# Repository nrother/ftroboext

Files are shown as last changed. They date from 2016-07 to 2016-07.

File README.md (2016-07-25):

# ftroboext
Self-made fischertechnik Robo Extension based on a ATmega328

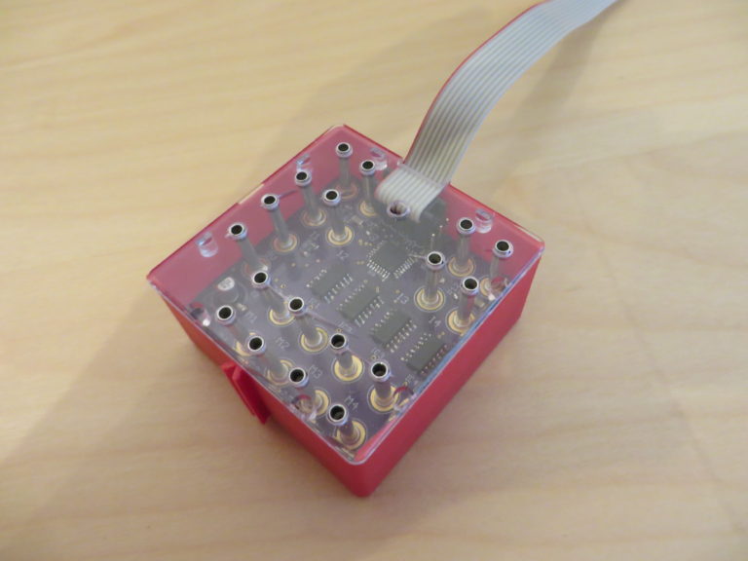
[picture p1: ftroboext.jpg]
Photo of ftroboext
 

I own a RoboInterface (yes, the old) from fischertechnik, but no
Extension module for it. It's difficult to find some now, so I build
my own. This repository contains the hardware as EAGLE files and the
software as an Arduino sketch. The PCB is designed to fit nicely into
a box (Art.Nr. 130961).

More information (in german) can be found on [my blog](http://niklas-rother.de/tags/ftroboext/).

I currently have two unpopulated PCBs here, contact me if you have interest
in them.

## Hardware
The hardware is quite packed because it has to fit inside the box. This is
also the reason why there are only four inputs (I1-I4). Everything is SMD
for the same reason, but can be hand-soldered quite well, the biggest problem
is the ATmega, but it is doable.

The hardware has a few bugs, see below. Some will be fixed in a new revision,
some are impossible to fix. The biggest problem is, that the voltage on
O2,O4,O6 and O8 can not be controlled, they are always the same as O1,O3,O5 and O7.
This is because the driver has only one enable pin for both outputs, a fact I
missed when selecting the chip.

### Revision A
* Footprint for C2 is wrong (too large)
* Footprints for the connectors are a bit large
* EXT header is mirrored/label is wrong
* The `/SS` pin is not pulled low. To fix this, cut the `ADDR1` pin from the header, solder
it to GND (the pin next to it) and remove R14.

## Software
The protocol for the extension module was reversed-engineered by *thkais* and
can be found [on this website](https://web.archive.org/web/20150218211103/http://www.ft-fanpage.de/roboint/roboext.html)

The current software implements the basic functionality. Analog values are not
implemented. Only a single extension, EXT1 is emulated and chaining is not supported.

## Disclaimer
This is project is not affiliated or endorsed by fischertechnik. It's just
a project by a fan.

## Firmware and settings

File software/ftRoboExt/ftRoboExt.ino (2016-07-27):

#include <SPI.h>

#define PIN_I1 A0
#define PIN_I2 A1
#define PIN_I3 A2
#define PIN_I4 A3

#define PIN_INB4 A5
#define PIN_INB3 0
#define PIN_INB2 1
#define PIN_INB1 2
#define PIN_INH4 3
#define PIN_INA3 4
#define PIN_INH2 5
#define PIN_INH1 6
#define PIN_INA2 7
//#define PIN_INA4 //PB6, which is not accessible from arduino (because it's XTAL1)
#define PIN_INA1 8
#define PIN_INH3 9

#define PIN_ADDR0 A4
#define PIN_ADDR1 10
#define PIN_DATA_IN 11
#define PIN_DATA_OUT 12
#define PIN_DATA_CLOCK 13
//#define PIN_EM_ACK //PB7, s.a

byte bufOut[6] = { 0x00, 0x00, 0x00, 110 /*330/3*/, 0x00, 0x00 };
byte bufIn[6] = { 0x00, 0x00, 0x00, 0x00, 0x00, 0x00 };
volatile byte pos;
byte debugDataOut = 0;
byte pwmLUT[8] = {77, 102, 128, 153, 179, 204, 230, 255}; //This matches the original robo interface, although we use 500Hz instead of 1kHz

#define SECOND_MODULE //if enabled, simulate a second EM for storing data.
/* The second EM is kind of hack purely based on timing because we cannot read
 * ADDR1 due to hardware restrictions (see below). In praxis this seems to work
 * quite well.
 */

void setup() {
  pinMode(PIN_I1, INPUT);
  pinMode(PIN_I2, INPUT);
  pinMode(PIN_I3, INPUT);
  pinMode(PIN_I4, INPUT);

  pinMode(PIN_INA1, OUTPUT);
  pinMode(PIN_INA2, OUTPUT);
  pinMode(PIN_INA3, OUTPUT);
  DDRB |= bit(6); //INA4 is OUTPUT
  pinMode(PIN_INB1, OUTPUT);
  pinMode(PIN_INB2, OUTPUT);
  pinMode(PIN_INB3, OUTPUT);
  pinMode(PIN_INB4, OUTPUT);
  pinMode(PIN_INH1, OUTPUT);
  pinMode(PIN_INH2, OUTPUT);
  pinMode(PIN_INH3, OUTPUT);
  pinMode(PIN_INH4, OUTPUT);

  pinMode(PIN_ADDR0, INPUT_PULLUP);
  //pinMode(PIN_ADDR1, INPUT_PULLUP); //WARNING: This is slave select, it must be low (HW bug!)
  /* I currently dont see a way to fix this in software. The !SS pin must be externally pulled
   * down in slave mode, so we loose this pin completly. In therory it would be enough to pull
   * it down after the address was detected, but we don't have a matching pin for that either.
   * Pulling this in down is easy in hardware, but we'll loose the ability to read ADDR1, and
   * therefore can listen only on one address (or on all even addresses to be more preceise).
   * We just have not enought pins :(
  */
  DDRB |= bit(7); //EM_ACK is OUTPUT

  pinMode(PIN_DATA_IN, INPUT_PULLUP);
  pinMode(PIN_DATA_OUT, OUTPUT);
  pinMode(PIN_DATA_CLOCK, INPUT_PULLUP);
  pos = 0;

  SPI.setDataMode(SPI_MODE3);
  SPI.attachInterrupt();
}

ISR (SPI_STC_vect) //SPI interrupt
{
  //read data from register
  bufIn[pos] = ~SPDR;
  //put next value in the register
  pos++;
  SPDR = ~bufOut[pos];

  digitalWriteEmAck(HIGH);
  delayMicroseconds(2);
  digitalWriteEmAck(LOW);
}

bool first = false;
void loop() {
  //wait for address
  if (first) while (digitalRead(PIN_ADDR0) == HIGH) {}
  else delayMicroseconds(50); //wait until master should have addressed us (this is just a guess!)
  
  //reset SPI module, just in case (system can hang up on startup otherwise)
  SPCR &= ~bit(SPE);
  SPCR |= bit(SPE);
  pos = 0;

  //read in data
  bufOut[0] = (digitalRead(PIN_I1) << 0) | (digitalRead(PIN_I2) << 1) | (digitalRead(PIN_I3) << 2) | (digitalRead(PIN_I4) << 3) | (debugDataOut & 0xF) << 4;
  //TODO: Analog values

  //put first byte in register
  SPDR = ~bufOut[0];

  delayMicroseconds(100); //700µs delay in original module, not sure if needed
  digitalWriteEmAck(LOW);

  if (first) while (digitalRead(PIN_ADDR0) == LOW) {} //wait for master to release address
  else {
    //wait for 6 bytes or 600µs timeout
    unsigned long start = micros();
    while(pos < 6 && (micros() - start) < 600) {}
  }

  delayMicroseconds(10);
  digitalWriteEmAck(HIGH);

  //process in data
  if (first) {
    digitalWrite(PIN_INA1, (bufIn[1] & bit(0)) != 0);
    digitalWrite(PIN_INB1, (bufIn[1] & bit(1)) != 0);
    digitalWrite(PIN_INA2, (bufIn[1] & bit(2)) != 0);
    digitalWrite(PIN_INB2, (bufIn[1] & bit(3)) != 0);
    digitalWrite(PIN_INA3, (bufIn[1] & bit(4)) != 0);
    digitalWrite(PIN_INB3, (bufIn[1] & bit(5)) != 0);
    digitalWriteInA4((bufIn[1] & bit(6)) != 0);
    digitalWrite(PIN_INB4, (bufIn[1] & bit(7)) != 0);
  
    //we ignore the even speeds, this will be the same as the odd due to hardware limitations. Maybe we can do some clever tricks to fix that...
    byte speed1 = bufIn[2] & 0x7;
    byte speed3 = ((bufIn[3] & 0x1) << 2) | ((bufIn[2] >> 6) & 0x3); //Yay, bit magic...
    byte speed5 = (bufIn[3] >> 4) & 0x7;
    byte speed7 = (bufIn[4] >> 2) & 0x7;
    
    analogWrite(PIN_INH1, pwmLUT[speed1]);
    analogWrite(PIN_INH2, pwmLUT[speed3]);
    analogWrite(PIN_INH3, pwmLUT[speed5]);
    analogWrite(PIN_INH4, pwmLUT[speed7]);
  }
  else delay(3); //the master will continue with EM3 so wait here until he gives up. Without this delay we sometimes recv data for EM3 as EM1!
  #ifdef SECOND_MODULE
  first = !first;
  #endif
}

void digitalWriteEmAck(byte val) {
  if (val == LOW)
    PORTB &= ~bit(7);
  else if (val == HIGH)
    PORTB |= bit(7);
}

void digitalWriteInA4(byte val) {
  if (val == LOW)
    PORTB &= ~bit(6);
  else if (val == HIGH)
    PORTB |= bit(6);
}

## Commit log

2016-07-25 Add intial version
    [ext_m8.brd, ext_m8.sch]
2016-07-25 Move Arduino sketch to a subfolder
    This is required by the arduino enviroment
2016-07-25 Use correct duty cycles
    These are directly measured from a original robo interface.
    [ftRoboExt.ino]
2016-07-27 Prototype of a second EM
    This is purely based on guessing the timing for the master, but seems to
    work quite well
